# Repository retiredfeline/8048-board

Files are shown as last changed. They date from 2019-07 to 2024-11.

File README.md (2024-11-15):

# 8048 board

This is the circuit design for a board using the 8048 MCU, initially intended to be a clock but can be used for other purposes. It can drive multiplexed 7 segment LEDs or a serial interface display using the TM1637 chip. The timer reference can be the onboard crystal, a DS128(8)7 clock chip, or mains.

In retrospect 7407s are probably better for the output buffers because if their input is high or floating, say the 8048 chip is removed, their output transistors will be non-conducting to ground, and less likely to burn out displays.

## Versioning

First release July 2019

## Authors

* **Ken Yap**

## License

See the [LICENSE](LICENSE.md) file for license rights and limitations (MIT).

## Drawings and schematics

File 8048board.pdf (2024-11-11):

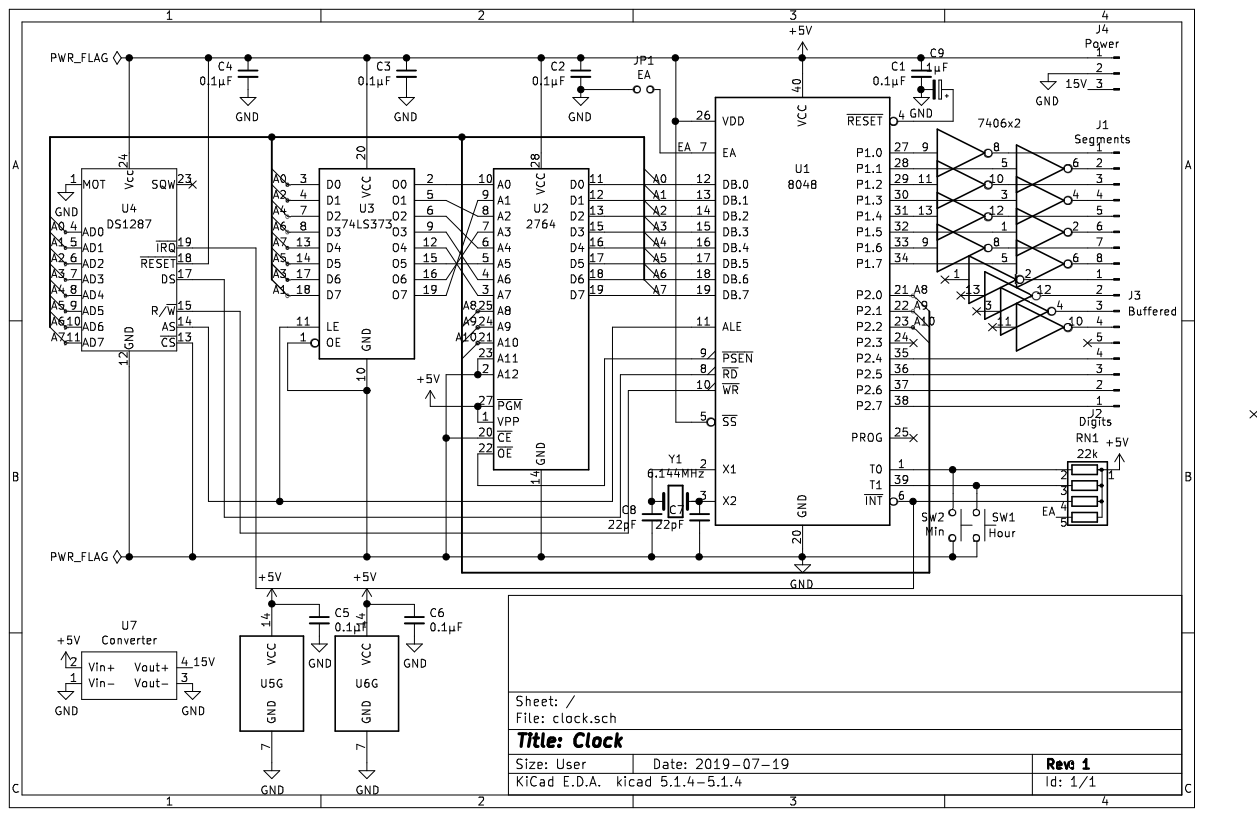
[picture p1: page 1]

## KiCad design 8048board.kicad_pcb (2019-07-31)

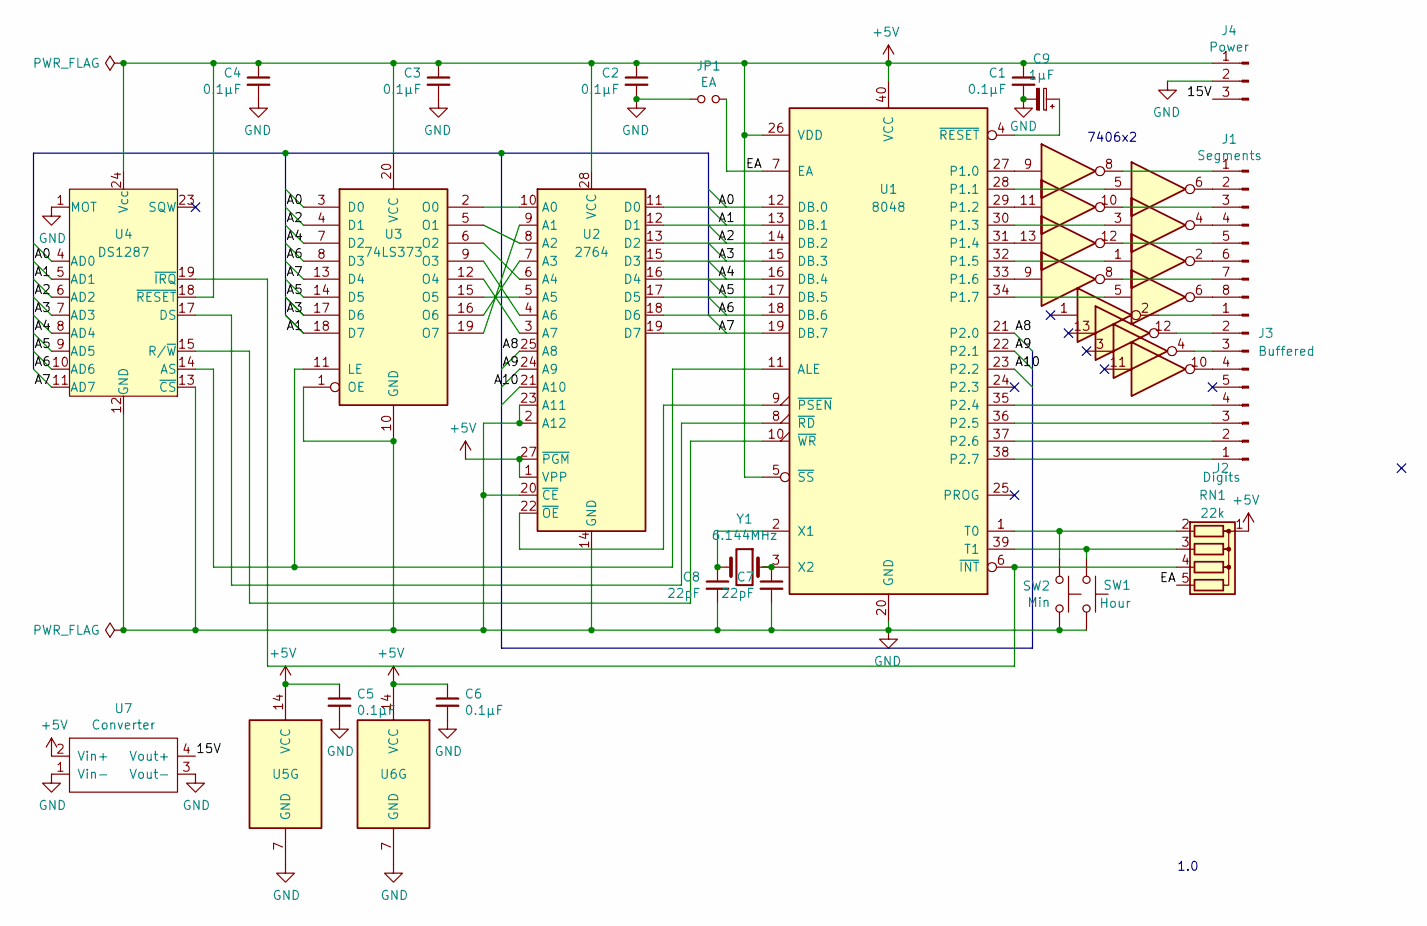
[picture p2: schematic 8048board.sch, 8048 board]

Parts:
C1, C2, C3, C4, C5, C6: 0.1µF; C_Rect_L7.0mm_W2.5mm_P5.00mm
C7, C8: 22pF; C_Disc_D3.0mm_W1.6mm_P2.50mm
C9: 1µF; CP_Radial_D5.0mm_P2.50mm
J1: Segments; PinHeader_1x08_P2.54mm_Vertical
J2: Digits; PinHeader_1x05_P2.54mm_Vertical
J3: Buffered; PinHeader_1x04_P2.54mm_Vertical
J4: Power; PinHeader_1x03_P2.54mm_Vertical
JP1: EA; PinHeader_1x02_P2.54mm_Vertical
RN1: 22k; R_Array_SIP5
SW1: Hour; SW_PUSH_6mm
SW2: Min; SW_PUSH_6mm
U1: 8048; DIP-40_W15.24mm
U2: 2764; DIP-28_W15.24mm
U3: 74LS373; DIP-20_W7.62mm
U4: DS1287; DIP-24_W15.24mm
U5, U6: 74LS06; DIP-14_W7.62mm
U7: Converter; Daughterboard_30.48x17.78_25.40x15.24
Y1: 6.144MHz; Crystal_HC18-U_Vertical

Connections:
+5V: C1.1, C2.1, C3.1, C4.1, C5.1, C6.1, J4.1, RN1.1 (common), U1.5 (~SS~), U1.26 (VDD), U1.40 (VCC), U2.1 (VPP), U2.27 (~PGM), U2.28 (VCC), U3.20 (VCC), U4.18 (~RESET~), U4.24 (Vcc), U5.14 (VCC), U6.14 (VCC), U7.2 (Vin+)
/15V: J4.3, U7.4 (Vout+)
/A0: U1.12 (DB.0), U2.11 (D0), U3.3 (D0), U4.4 (AD0)
/A1: U1.13 (DB.1), U2.12 (D1), U3.18 (D7), U4.5 (AD1)
/A2: U1.14 (DB.2), U2.13 (D2), U3.4 (D1), U4.6 (AD2)
/A3: U1.15 (DB.3), U2.15 (D3), U3.17 (D6), U4.7 (AD3)
/A4: U1.16 (DB.4), U2.16 (D4), U3.7 (D2), U4.8 (AD4)
/A5: U1.17 (DB.5), U2.17 (D5), U3.14 (D5), U4.9 (AD5)
/A6: U1.18 (DB.6), U2.18 (D6), U3.8 (D3), U4.10 (AD6)
/A7: U1.19 (DB.7), U2.19 (D7), U3.13 (D4), U4.11 (AD7)
/A8: U1.21 (P2.0), U2.25 (A8)
/A9: U1.22 (P2.1), U2.24 (A9)
/A10: U1.23 (P2.2), U2.21 (A10)
/EA: JP1.1, RN1.5 (R4), U1.7 (EA)
GND: C1.2, C2.2, C3.2, C4.2, C5.2, C6.2, C7.2, C8.2, C9.2, J4.2, JP1.2, SW1.2, SW2.1, U1.20 (GND), U2.2 (A12), U2.14 (GND), U2.20 (~CE), U2.23 (A11), U3.1 (OE), U3.10 (GND), U4.1 (MOT), U4.12 (GND), U4.13 (~CS~), U5.7 (GND), U6.7 (GND), U7.1 (Vin-), U7.3 (Vout-)
unnamed: C7.1, U1.3 (X2), Y1.1
unnamed: C8.1, U1.2 (X1), Y1.2
unnamed: C9.1, U1.4 (~RESET~)
unnamed: J1.1, U5.8
unnamed: J1.2, U5.6
unnamed: J1.3, U5.10
unnamed: J1.4, U5.4
unnamed: J1.5, U5.12
unnamed: J1.6, U5.2
unnamed: J1.7, U6.8
unnamed: J1.8, U6.6
unnamed: J2.1, U1.38 (P2.7)
unnamed: J2.2, U1.37 (P2.6)
unnamed: J2.3, U1.36 (P2.5)
unnamed: J2.4, U1.35 (P2.4)
unnamed: J3.1, U6.2
unnamed: J3.2, U6.12
unnamed: J3.3, U6.4
unnamed: J3.4, U6.10
unnamed: RN1.2 (R1), SW2.2, U1.1 (T0)
unnamed: RN1.3 (R2), SW1.1, U1.39 (T1)
unnamed: RN1.4 (R3), U1.6 (~INT~), U4.19 (~IRQ~)
unnamed: U1.8 (~RD~), U4.17 (DS)
unnamed: U1.9 (~PSEN~), U2.22 (~OE)
unnamed: U1.10 (~WR~), U4.15 (R/~W~)
unnamed: U1.11 (ALE), U3.11 (LE), U4.14 (AS)
unnamed: U1.27 (P1.0), U5.9
unnamed: U1.28 (P1.1), U5.5
unnamed: U1.29 (P1.2), U5.11
unnamed: U1.30 (P1.3), U5.3
unnamed: U1.31 (P1.4), U5.13
unnamed: U1.32 (P1.5), U5.1
unnamed: U1.33 (P1.6), U6.9
unnamed: U1.34 (P1.7), U6.5
unnamed: U2.3 (A7), U3.12 (O4)
unnamed: U2.4 (A6), U3.9 (O3)
unnamed: U2.5 (A5), U3.15 (O5)
unnamed: U2.6 (A4), U3.6 (O2)
unnamed: U2.7 (A3), U3.16 (O6)
unnamed: U2.8 (A2), U3.5 (O1)
unnamed: U2.9 (A1), U3.19 (O7)
unnamed: U2.10 (A0), U3.2 (O0)

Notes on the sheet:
1.0
7406x2

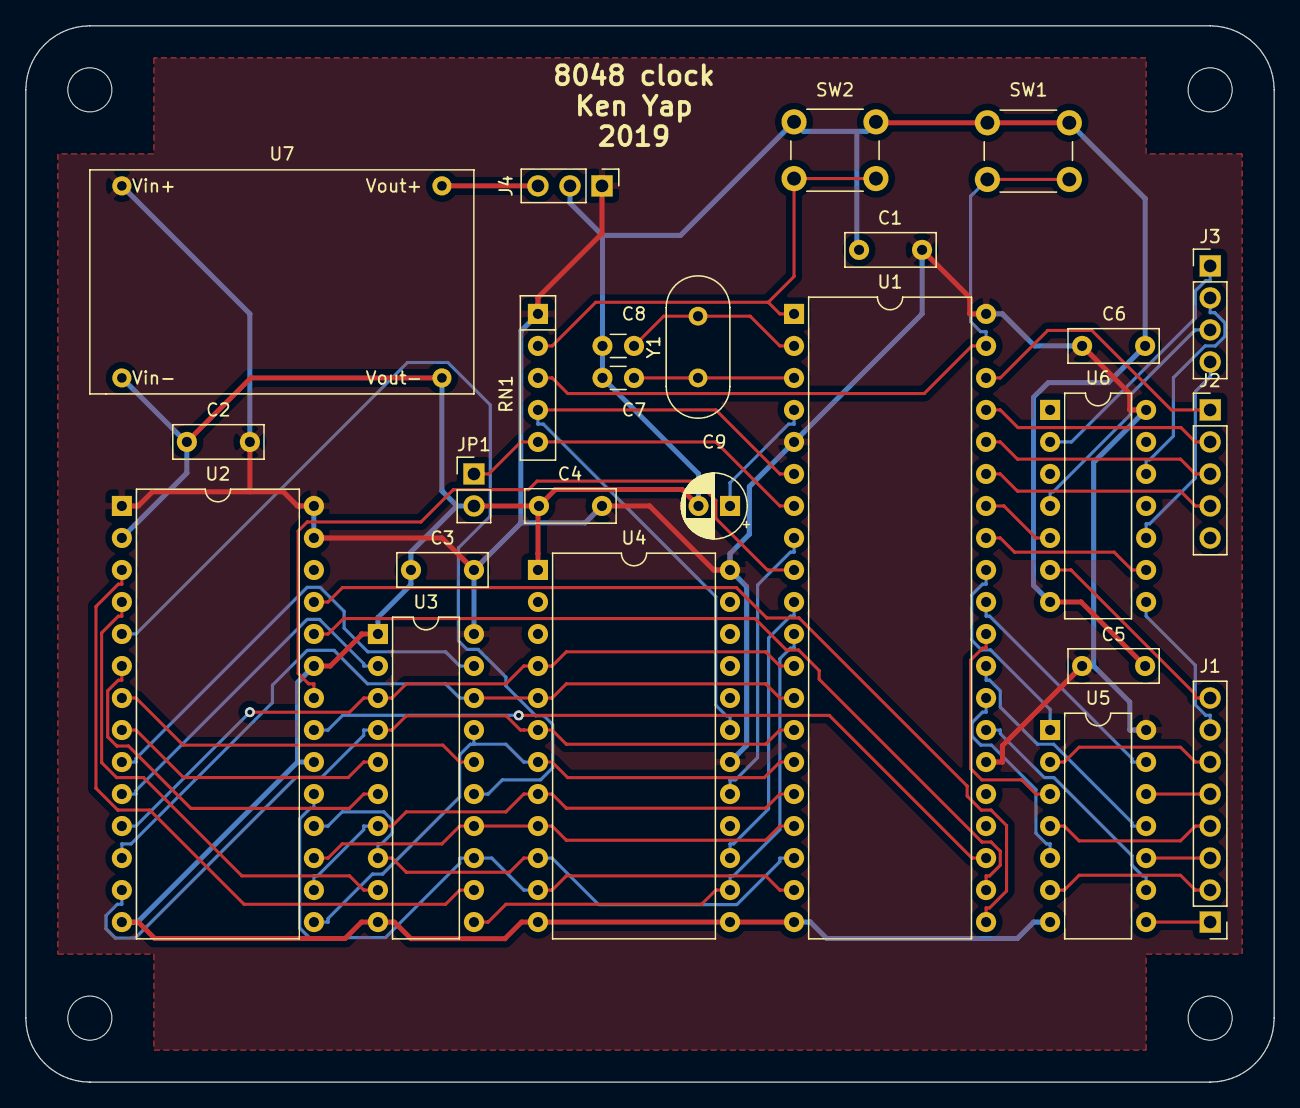
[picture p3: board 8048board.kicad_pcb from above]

Board: 2 copper layers, 99.1 x 83.8 mm, 30 parts (1 on the bottom side), 57 nets.

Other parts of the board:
H1, H2, H3, H4: MountingHole_3.5mm
K1: KiCad-Logo_5mm_SilkScreen

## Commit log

2019-07-31 Publish board design
    [clock-B_Cu.gbl, clock-B_Mask.gbs, clock-B_SilkS.gbo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]
2019-11-15 Add PDF of schematic
